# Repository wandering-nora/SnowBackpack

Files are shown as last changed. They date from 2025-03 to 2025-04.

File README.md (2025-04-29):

# SnowBackpack
Cute ESP32-C3 backpack for 2 x n [SnowPixel](https://github.com/wandering-nora/SnowPixel) matrix displays.

This board can power a grid of 2+ SnowPixel displays without any wiring in a thin package.

The main features are:
- ESP8685H4 RISC-V mcu with 4MB of flash, Wifi and BLE @160MHz
- Battery charging for protected 1s lipo cells
- ST LSM6DSO 6-axis low power accelerometer
- Efficient 5V boost converter with 500mA max current for the SnowPixel modules
- Onboard ceramic antenna

The board has no power switch, the MCU can deep sleep and be woken up by the always on IMU with two interrupt pins. The 5V boost converter can also be switched off leaving only the 3.3V rail and IMU operational for very low static power consumption.

> Note:  for normal operation R13 and R14  are unpopulated

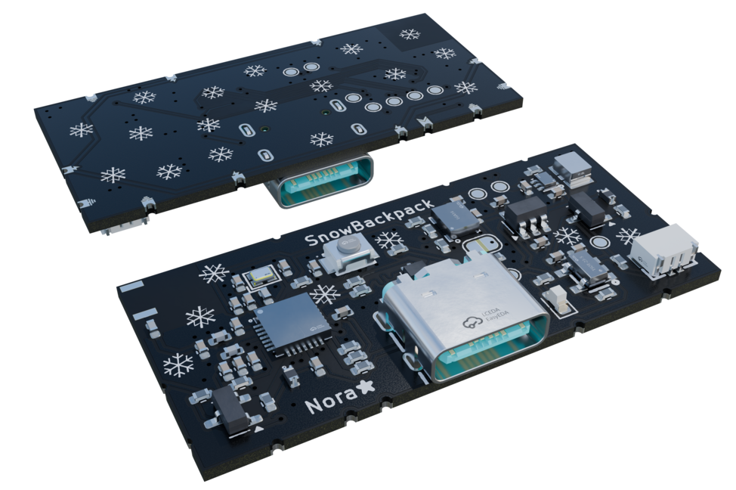
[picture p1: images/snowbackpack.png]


## Manufacturing update
After assembly with a hot plate everything works as intended ^_^  
There's only a couple of things I would change for V1.2 which should keep my stencil mostly reusable.

#### Todo for V1.2
- [ ] Get rid of jumper on data out pad
- [ ] Change battery connector to a 1A capable one
- [ ] Consider removing extra pads on long edge

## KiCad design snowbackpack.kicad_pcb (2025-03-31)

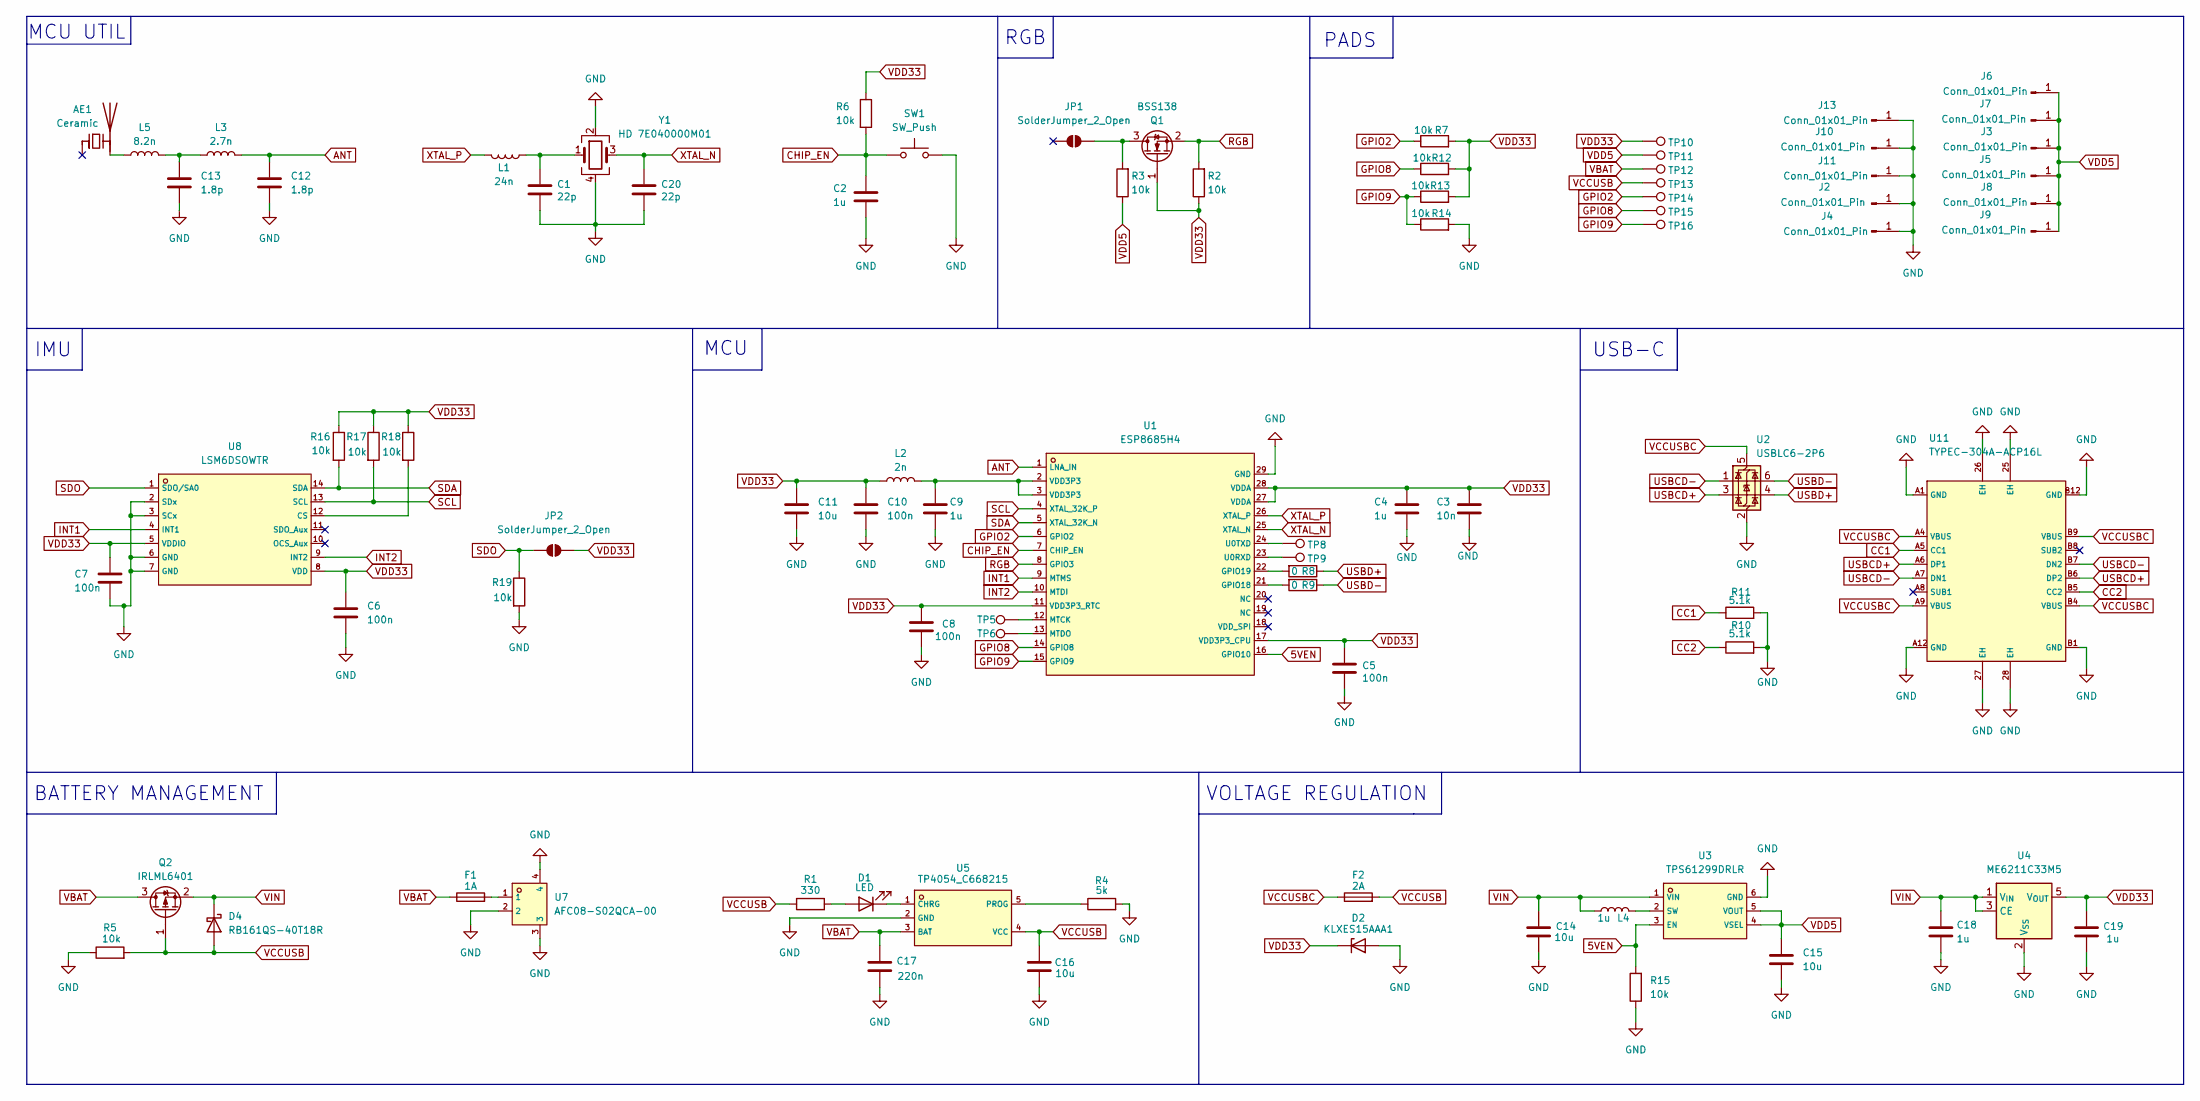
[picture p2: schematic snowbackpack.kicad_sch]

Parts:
AE1: Ceramic; CW324S
C1, C20: 22p; C_0402_1005Metric
C2, C4, C9, C18, C19: 1u; C_0402_1005Metric
C3: 10n; C_0402_1005Metric
C5, C6, C7, C8, C10: 100n; C_0402_1005Metric
C11, C14, C15, C16: 10u; C_0402_1005Metric
C12, C13: 1.8p; C_0402_1005Metric
C17: 220n; C_0402_1005Metric
D1: LED; LED_0603_1608Metric
D2: KLXES15AAA1; D_0402_1005Metric
D4: RB161QS-40T18R; D_0402_1005Metric
F1: 1A; Fuse_0402_1005Metric
F2: 2A; Fuse_0402_1005Metric
J2, J4, J10, J11, J13: Conn_01x01_Pin; matrix-pad-gn
J3, J5, J6, J7, J8, J9: Conn_01x01_Pin; matrix-pad-vcc
JP1: SolderJumper_2_Open; matrix-pad-dout
JP2: SolderJumper_2_Open; SolderJumper-2_P1.3mm_Open_RoundedPad1.0x1.5mm
L1: 24n; L_0402_1005Metric
L2: 2n; L_0402_1005Metric
L3: 2.7n; L_0402_1005Metric
L4: 1u; IND-SMD_L2.5-W2.0
L5: 8.2n; L_0402_1005Metric
Q1: BSS138; SOT-23
Q2: IRLML6401; SOT-23
R1: 330; R_0402_1005Metric
R2, R3, R5, R6, R7, R12, R13, R14, R15, R16, R17, R18, R19: 10k; R_0402_1005Metric
R4: 5k; R_0402_1005Metric
R8, R9: 0; R_0402_1005Metric
R10, R11: 5.1k; R_0402_1005Metric
SW1: SW_Push; KEY-SMD_B3U-1000PM
TP5, TP6, TP8, TP9, TP10, TP11, TP12, TP13, TP14, TP15, TP16: TestPoint; TestPoint_Pad_D1.0mm
U1: ESP8685H4; QFN-28_L4.0-W4.0-P0.40-TL-EP2.7; LCSC C4944062
U2: USBLC6-2P6; SOT-666
U3: TPS61299DRLR; SOT-563-6_L1.6-W1.2-P0.50-LS1.6-BL; LCSC C41689719
U4: ME6211C33M5; SOT-23-5
U5: TP4054_C668215; TSOT-23-5_L2.9-W1.6-P0.95-LS2.8-BR; LCSC C668215
U7: AFC08-S02QCA-00; CONN-SMD_2P-P0.80_JUSHUO_AFC08-S02QCA-00; LCSC C2934855
U8: LSM6DSOWTR; LGA-14L_L3.0-W2.5-P0.50-TL; LCSC C2829074
U11: TYPEC-304A-ACP16L; USB-C-SMD_XUNPU_TYPEC-304A-ACP16L; LCSC C2909609
Y1: HD 7E040000M01; CRYSTAL-SMD_4P-L1.6-W1.2-BL

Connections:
5VEN: R15.2, U1.16 (GPIO10), U3.3 (EN)
ANT: C12.2, L3.2, U1.1 (LNA_IN)
CC1: R11.1, U11.A5 (CC1)
CC2: R10.1, U11.B5 (CC2)
CHIP_EN: C2.1, R6.2, SW1.1, U1.7 (CHIP_EN)
GND: C1.2, C2.2, C3.2, C4.2, C5.1, C6.2, C7.2, C8.1, C9.2, C10.2, C11.2, C12.1, C13.1, C14.1, C15.2, C16.1, C17.1, C18.2, C19.1, C20.2, D2.2 (A), J2.1, J4.1, J10.1, J11.1, J13.1, R4.2, R5.1, R10.2, R11.2, R14.2, R15.1, R19.2, SW1.2, U1.29 (GND), U2.2 (GND), U3.6 (GND), U4.2 (V_{SS}), U5.2 (GND), U7.2, U7.3, U7.4, U8.2 (SDx), U8.3 (SCx), U8.6 (GND), U8.7 (GND), U11.25 (EH), U11.26 (EH), U11.27 (EH), U11.28 (EH), U11.A1 (GND), U11.A12 (GND), U11.B1 (GND), U11.B12 (GND), Y1.2, Y1.4
GPIO2: R7.1, TP14.1, U1.6 (GPIO2)
GPIO8: R12.1, TP15.1, U1.14 (GPIO8)
GPIO9: R13.1, R14.1, TP16.1, U1.15 (GPIO9)
INT1: U1.9 (MTMS), U8.4 (INT1)
INT2: U1.10 (MTDI), U8.9 (INT2)
unnamed: AE1.2 (PCB_Trace), L5.1
unnamed: C1.1, L1.1, Y1.1
unnamed: C9.1, L2.2, U1.2 (VDD3P3), U1.3 (VDD3P3)
unnamed: C13.2, L3.1, L5.2
unnamed: D1.2 (A), R1.2
unnamed: D1.1 (K), U5.1 (CHRG)
unnamed: F1.2, U7.1
unnamed: JP1.2 (B), Q1.3 (D), R3.2
unnamed: R9.2, U1.21 (GPIO18)
unnamed: R8.2, U1.22 (GPIO19)
unnamed: TP5.1, U1.12 (MTCK)
unnamed: TP6.1, U1.13 (MTDO)
unnamed: TP9.1, U1.23 (U0RXD)
unnamed: TP8.1, U1.24 (U0TXD)
unnamed: L4.2, U3.2 (SW)
unnamed: R4.1, U5.5 (PROG)
unnamed: R18.2, U8.12 (CS)
RGB: Q1.2 (S), R2.2, U1.8 (GPIO3)
SCL: R17.2, U1.4 (XTAL_32K_P), U8.13 (SCL)
SDA: R16.2, U1.5 (XTAL_32K_N), U8.14 (SDA)
SDO: JP2.2 (B), R19.1, U8.1 (SDO/SA0)
USBCD+: U2.3 (I/O2), U11.A6 (DP1), U11.B6 (DP2)
USBCD-: U2.1 (I/O1), U11.A7 (DN1), U11.B7 (DN2)
USBD+: R8.1, U2.4 (I/O2)
USBD-: R9.1, U2.6 (I/O1)
VBAT: C17.2, F1.1, Q2.3 (D), TP12.1, U5.3 (BAT)
VCCUSB: C16.2, D4.2 (A), F2.2, Q2.1 (G), R1.1, R5.2, TP13.1, U5.4 (VCC)
VCCUSBC: F2.1, U2.5 (VBUS), U11.A4 (VBUS), U11.A9 (VBUS), U11.B4 (VBUS), U11.B9 (VBUS)
VDD5: C15.1, J3.1, J5.1, J6.1, J7.1, J8.1, J9.1, R3.1, TP11.1, U3.4 (VSEL), U3.5 (VOUT)
VDD33: C3.1, C4.1, C5.2, C6.1, C7.1, C8.2, C10.1, C11.1, C19.2, D2.1 (K), JP2.1 (A), L2.1, Q1.1 (G), R2.1, R6.1, R7.2, R12.2, R13.2, R16.1, R17.1, R18.1, TP10.1, U1.11 (VDD3P3_RTC), U1.17 (VDD3P3_CPU), U1.27 (VDDA), U1.28 (VDDA), U4.5 (V_{OUT}), U8.5 (VDDIO), U8.8 (VDD)
VIN: C14.2, C18.1, D4.1 (K), L4.1, Q2.2 (S), U3.1 (VIN), U4.1 (V_{IN}), U4.3 (CE)
XTAL_N: C20.1, U1.25 (XTAL_N), Y1.3
XTAL_P: L1.2, U1.26 (XTAL_P)

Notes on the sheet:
IMU
VOLTAGE REGULATION
MCU UTIL
BATTERY MANAGEMENT
PADS
MCU
RGB
USB-C

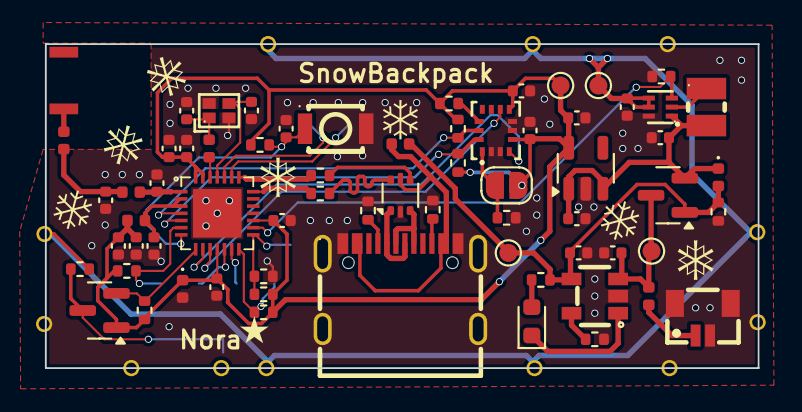
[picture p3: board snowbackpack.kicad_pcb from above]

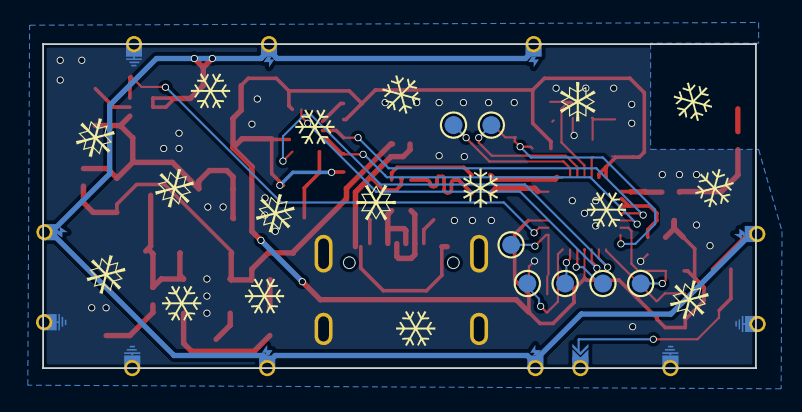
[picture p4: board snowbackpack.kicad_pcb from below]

Board: 2 copper layers, 39.6 x 18.0 mm, 86 parts (19 on the bottom side), 44 nets.

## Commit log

2025-03-12 First pcb routing
    [snowbackpack.kicad_pcb, snowbackpack.kicad_sch]
2025-03-12 Fixed smd antenna
    [snowbackpack.kicad_pcb, snowbackpack.kicad_sch]
2025-03-12 Routed USB
    [snowbackpack.kicad_pcb, snowbackpack.kicad_sch]
2025-03-12 Update pcb silkscreen
    [snowbackpack.kicad_pcb]
2025-03-12 Updated silkscreen with snowflakes
    [snowbackpack.kicad_pcb]
2025-03-12 Slightly reduce clutter on silkscreen
    [snowbackpack.kicad_pcb]
2025-03-13 Fixed interconnect spacing
    [snowbackpack.kicad_pcb]
2025-03-15 Added v1 gerber files
    [snowbackpack-B_Cu.gbl, snowbackpack-B_Mask.gbs, snowbackpack-B_Paste.gbp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]
2025-03-17 added BOM and cleaned up schematics
    [snowbackpack.csv, snowbackpack.kicad_pcb, snowbackpack.kicad_sch]
2025-03-17 Updated BOM
    [snowbackpack.csv, snowbackpack.kicad_pcb, snowbackpack.kicad_sch]
2025-03-18 Change folder structure for release
    [snowbackpack-B_Cu.gbl, snowbackpack-B_Mask.gbs, snowbackpack-B_Paste.gbp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]
2025-03-31 Fix 3d models
    [snowbackpack.kicad_pcb]
